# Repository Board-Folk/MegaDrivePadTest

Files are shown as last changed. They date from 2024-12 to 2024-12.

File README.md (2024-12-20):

# Mega Drive Pad Tester

Simple testing device for Mega Drive/Genesis controllers.

Does not support the extra functionality of a 6-button pad.

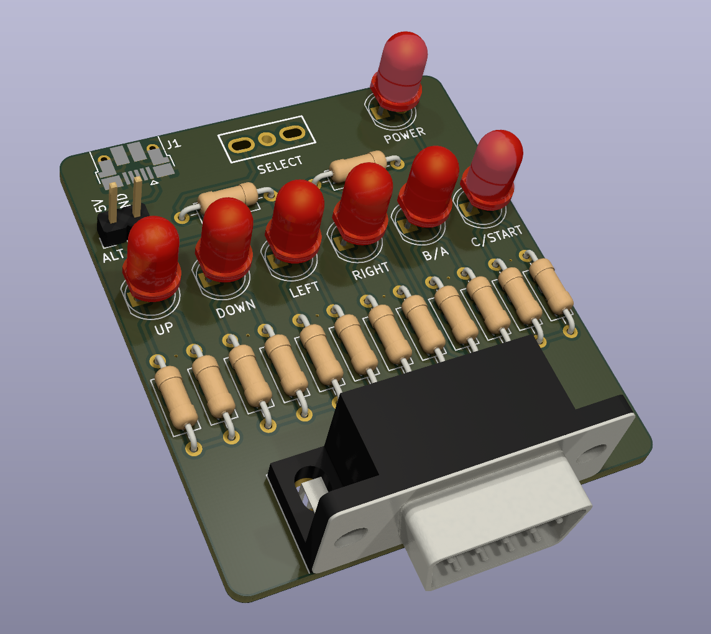
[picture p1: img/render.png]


## Bill of Materials

| Part | Quantity |
|---|---|
| LED 5mm | 7 |
| Resistor 10K (THT or 0805) | 7 |
| Resistor 270Ω (THT or 0805)  | 7 |
| SPDT slide switch | 1 |
| Right angle DE9 (male) | 1 |
| USB Micro port | 1\* |
| 2-pin header 2.54mm pitch | 1\* |

\* For power, either or both may be installed.

## How to Use

* Connect controller to DE9 port
* Apply +5V power though USB port or alternate power header.
* With SELECT switch in left position, LEDs will illuninate for Up, Down, Left, Right, B and C.
* With SELECT switch in right position, LEDs will illuninate for Up, Down, A and Start.
  (Left and Right will both remain illuminated, this is normal).

## License

Public domain.

## Legal

You are free to produce PCBs based on this project's designs at your own risk
and without limitation, for your own use or for sale and/or repair at a
reasonable price. Attribution is appreciated. The authors are not obliged to
provide support of any kind.

Under no circumstances will the authors be held responsible or liable in any
way for losses, damages or costs resulting from the use of the information
and/or resources of this project.

The resources are provided "as-is" without warranty of any kind, either
expressed or implied, including, but not limited to, the implied warranties
of merchantability and fitness for a particular purpose.

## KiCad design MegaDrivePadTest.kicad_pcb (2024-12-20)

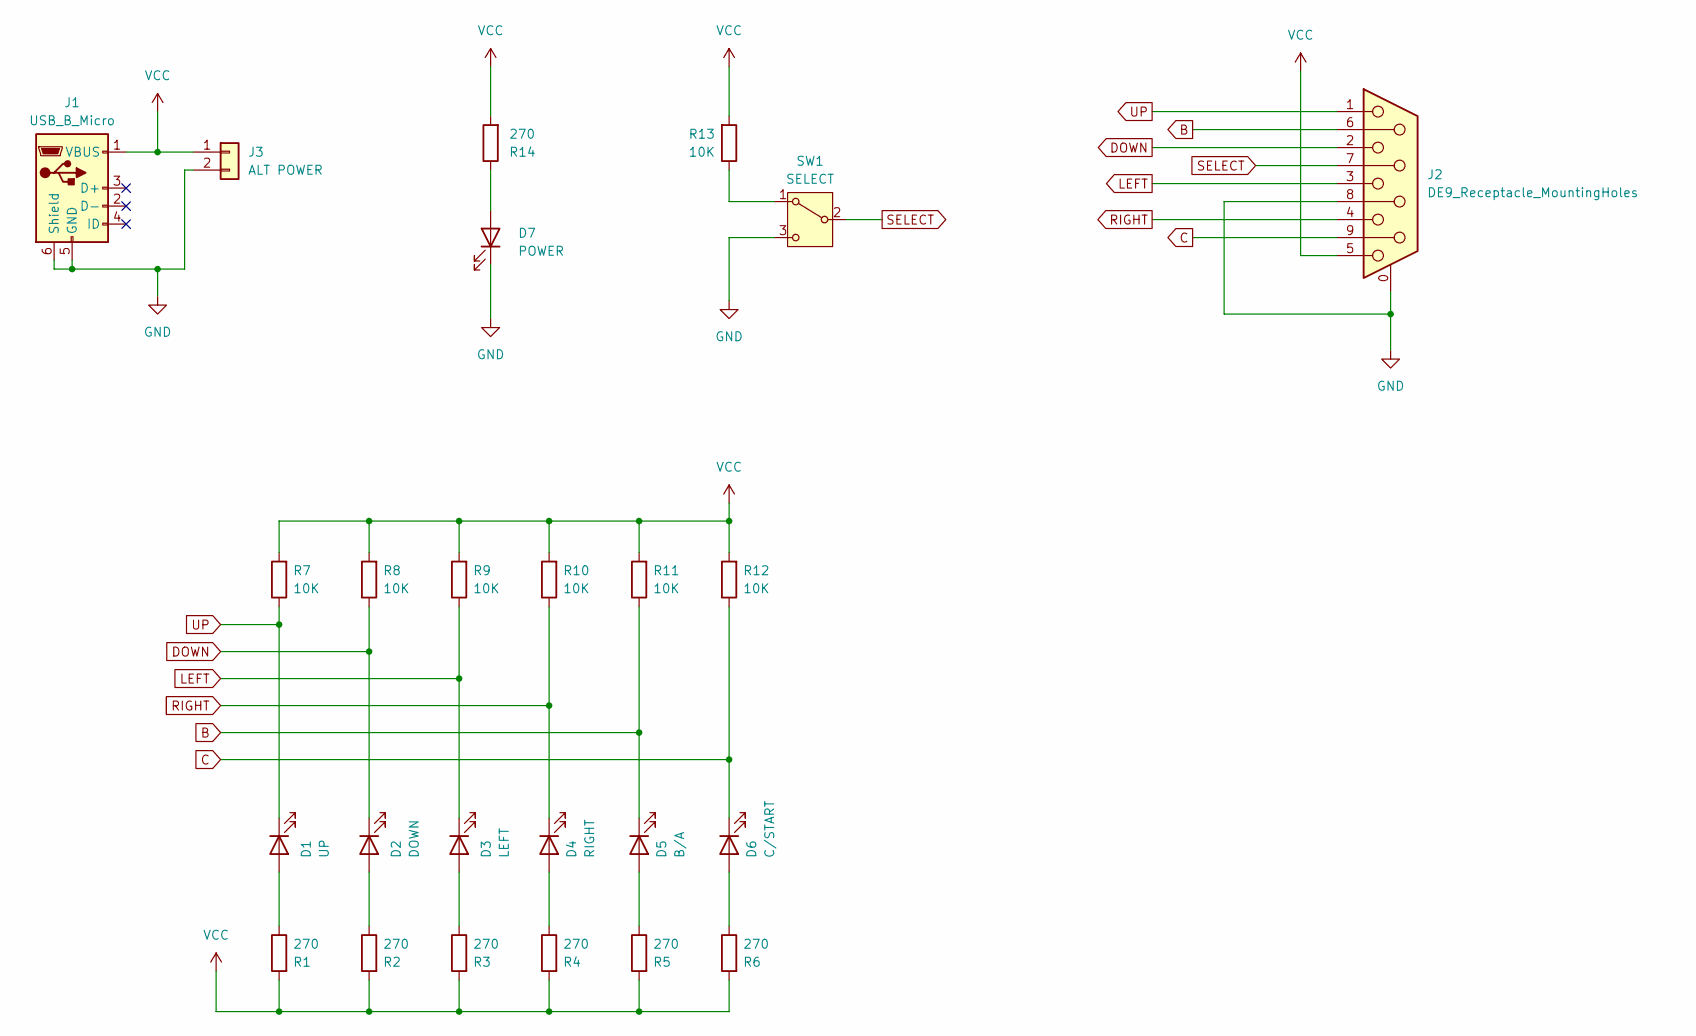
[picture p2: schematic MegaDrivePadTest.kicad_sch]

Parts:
D1: UP; LED_D5.0mm
D2: DOWN; LED_D5.0mm
D3: LEFT; LED_D5.0mm
D4: RIGHT; LED_D5.0mm
D5: B/A; LED_D5.0mm
D6: C/START; LED_D5.0mm
D7: POWER; LED_D5.0mm
J1: USB_B_Micro; USB_Micro-B_Amphenol_10103594-0001LF_Horizontal
J2: DE9_Receptacle_MountingHoles; DSUB-9_Male_Horizontal_P2.77x2.84mm_EdgePinOffset4.94mm_Hou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
J3: ALT POWER; PinHeader_1x02_P2.54mm_Vertical
R1, R2, R3, R4, R5, R6, R14: 270; R_Combo
R7, R8, R9, R10, R11, R12, R13: 10K; R_Combo
SW1: SELECT; Switch

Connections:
B: D5.1 (K), J2.6, R11.1
C: D6.1 (K), J2.9, R12.1
DOWN: D2.1 (K), J2.2, R8.1
GND: D7.1 (K), J1.5 (GND), J1.6 (Shield), J2.0 (PAD), J2.8, J3.2, SW1.3 (C)
LEFT: D3.1 (K), J2.3, R9.1
unnamed: D1.2 (A), R1.1
unnamed: D2.2 (A), R2.1
unnamed: D3.2 (A), R3.1
unnamed: D4.2 (A), R4.1
unnamed: D5.2 (A), R5.1
unnamed: D6.2 (A), R6.1
unnamed: D7.2 (A), R14.1
unnamed: R13.1, SW1.1 (A)
RIGHT: D4.1 (K), J2.4, R10.1
SELECT: J2.7, SW1.2 (B)
UP: D1.1 (K), J2.1, R7.1
VCC: J1.1 (VBUS), J2.5, J3.1, R1.2, R2.2, R3.2, R4.2, R5.2, R6.2, R7.2, R8.2, R9.2, R10.2, R11.2, R12.2, R13.2, R14.2

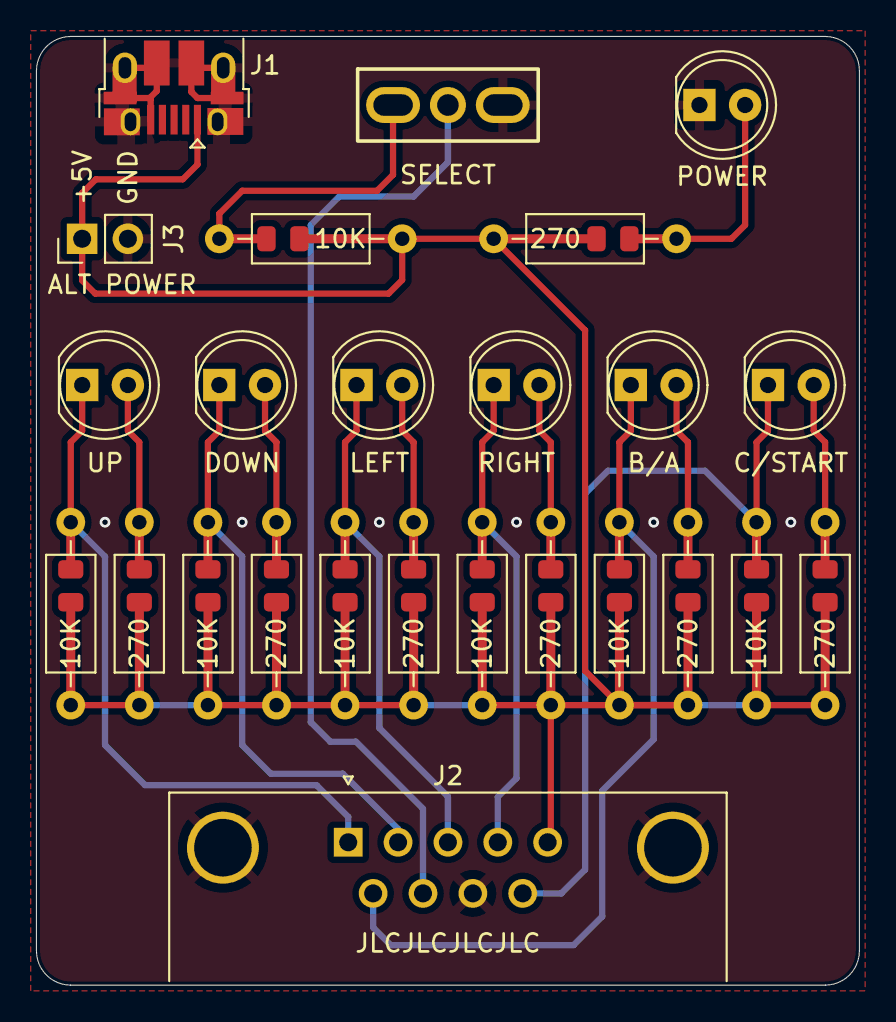
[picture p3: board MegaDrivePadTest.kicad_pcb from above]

Board: 2 copper layers, 45.7 x 52.7 mm, 25 parts (0 on the bottom side), 17 nets.

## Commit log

2024-12-05 Move USB port to edge of PCB.
    [MegaDrivePadTest.kicad_pcb]
2024-12-20 Allow for wider switches.
    [MegaDrivePadTest.kicad_pcb]
